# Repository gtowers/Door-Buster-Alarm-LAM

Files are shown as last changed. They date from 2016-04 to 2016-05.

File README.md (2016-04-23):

# Door-Buster-Alarm-LAM
This project is to develop a battery operated magnetic box that will be attached to manufacturing panels at LAM. 
The box has several criteria, but the most important ones are that the box detect panel doors when they are opened.  I have tested this once when the only requirement was that the siren go off for 20 seconds and a light continues to flash until the operator corrects the situation. The customer tested the box, and then came back with several new criteria.  Perhaps unfortunately, but certain decisions have been made, that I do not want to change at this point.    They are as follows:
1)  The battery is required to last 7 days 24 hours a day without the need of a recharge.  This is a customer requirement.
2)  The battery will be 12VDC, that is because the sensor I chose to use requres 11 VDC minimum.  I have chosen an allen-bradley photodetector.
3)   The customer has requested that there be some way that administration can look at the history as the box travels down the "assembly line".  Creating a history of when the box has alarmed.
4)   The customer wants a protective "cage" for the alarm and horn so that if dropped, the beacon/horn won't be damaged.
5)  I am using a lithium polymer battery.  Charging this battery requires a "2 cable" set up.  The customer would like this to become a more simple 1 cable plug
6)  The customer wants a battery sensor that will let them know when the battery is drained to make sure that the battery is charged whenever required.
7)  The customer did not like the looks of the box.  I found a local vendor who has provided me with a box of brushed stainless steel, so this requirement has been satisfied.

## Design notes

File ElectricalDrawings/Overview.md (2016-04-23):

The first sketch, done in autocad electric - only used the arduino, photoelectric sensor and some relays.  
Rev 2_1 is the system broken down and is simply the voltage regulator to change voltage from 12 Volts, used for the arduino down to 3.2 Volts so that I can add the XBee as a stand alone.  My idea is to have it in sleep mode.  It's function is to be in sleep mode it will be used to track the remaining power on the battery.
The drawings are also converted to PDF for general review.

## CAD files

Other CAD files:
ElectricalDrawings/E01_R3.dwg
ElectricalDrawings/E01_R2.dwg
ElectricalDrawings/E01.dwg

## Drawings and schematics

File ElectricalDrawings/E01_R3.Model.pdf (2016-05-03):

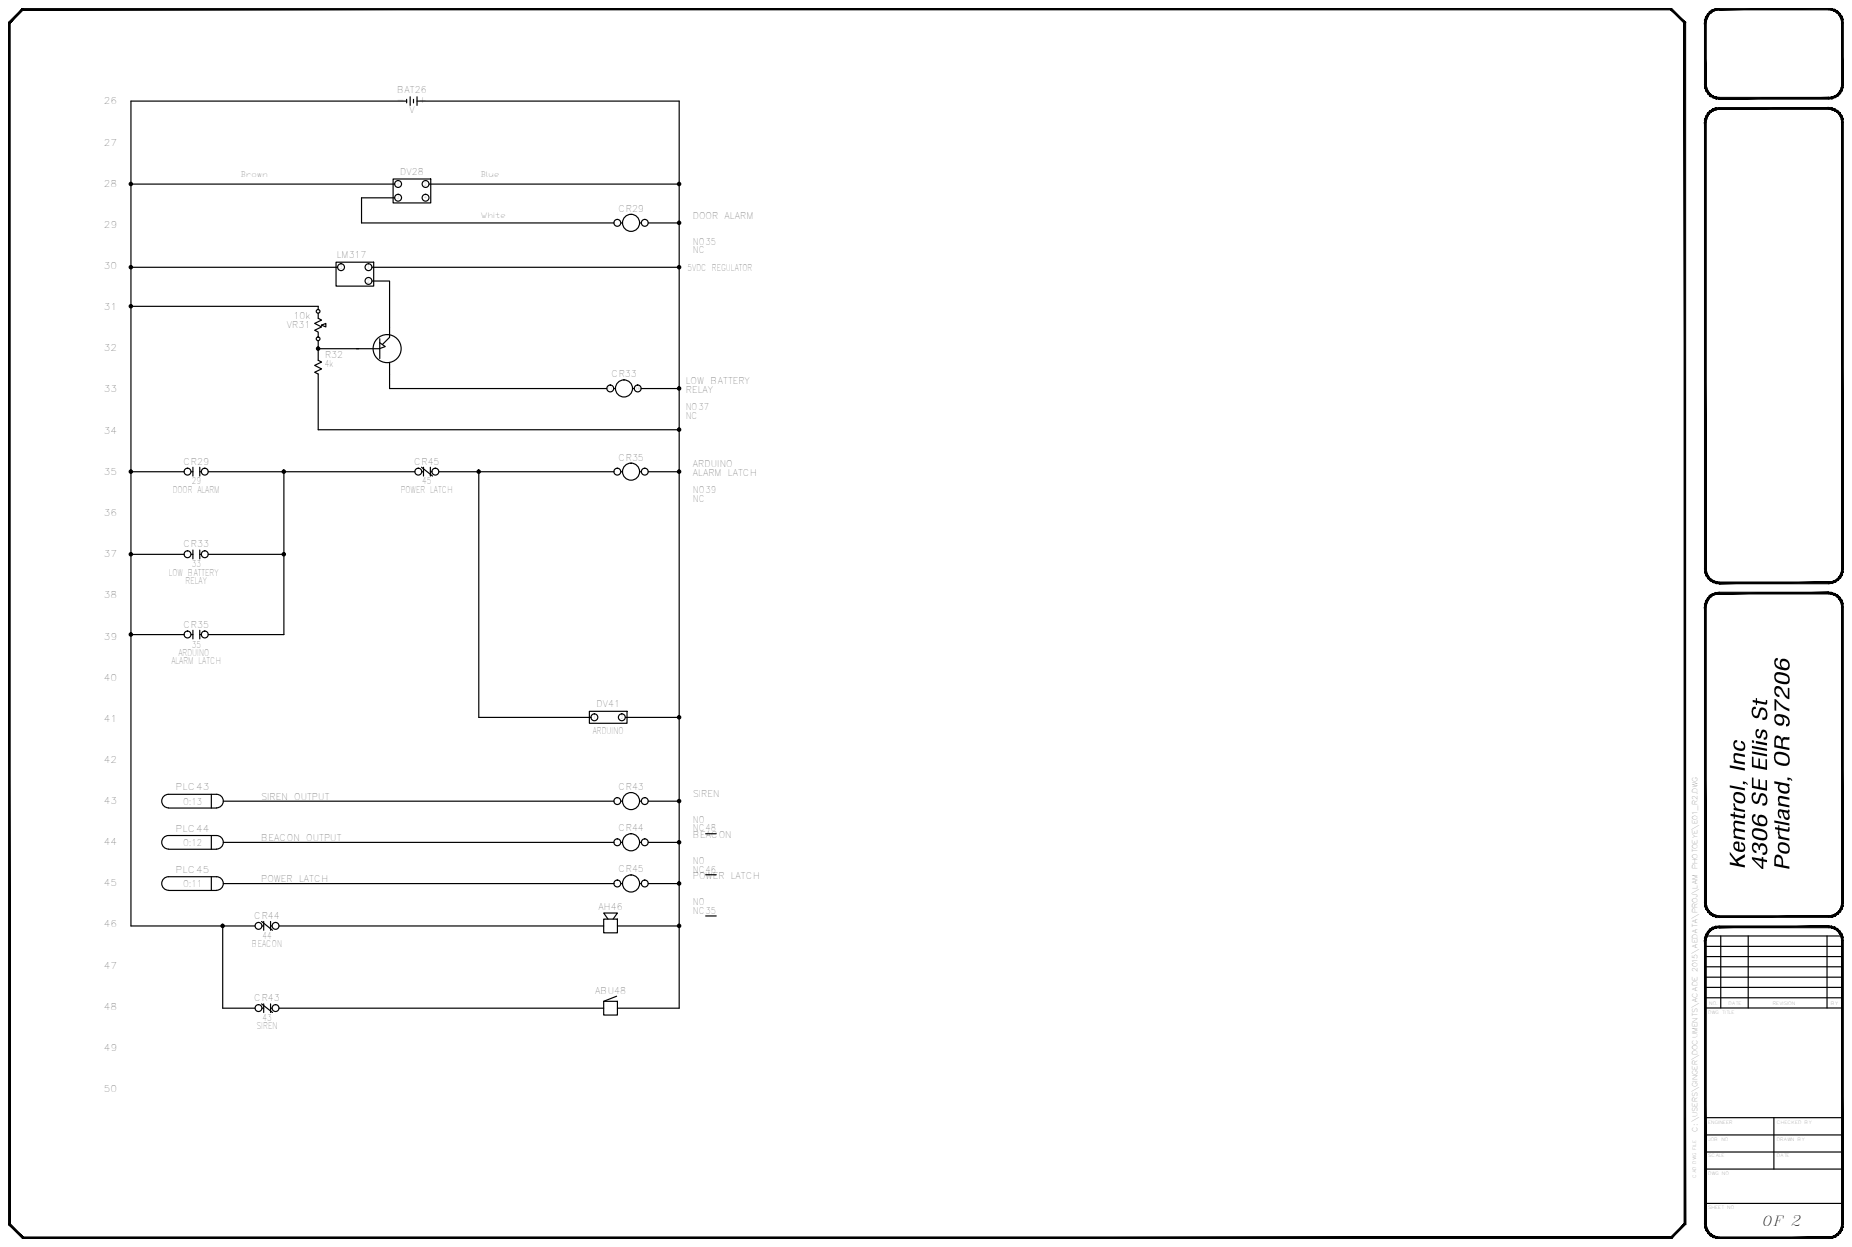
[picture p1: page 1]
DATE; REVISION; BY DWG TITLE; CHECKED BY DRAWN BY DATE ENGINEER JOB NO DWG NO CAD DWG FILE; SCALE; OF SHEET NO; + BAT26; 2 Brown; Blue; NCNO35 DOOR ALARM CR29 AH46 ABU48 PLC43; SIREN OUTPUT O:13; NCNO48 SIREN CR43 PLC44; BEACON OUTPUT O:12; NCNO46 BEACON CR44 PLC45; POWER LATCH O:11; NCNO35 POWER LATCH CR45 44 BEACON CR44 43 SIREN CR43; 5VDC REGULATOR; NCNO37 RELAY LOW BATTERY CR33; NCNO39 ALARM LATCH ARDUINO CR35 29 DOOR ALARM CR29 33 RELAY LOW BATTERY CR33 35 ALARM LATCH ARDUINO CR35; White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

C:\USERS\GINGER\DOCUMENTS\ACADE 2015\AEDATA\PROJ\LAM PHOTOEYE\E01_R2.DWG 26272829303132333435363738394041424344454647484950

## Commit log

2016-04-24 Create Arduino-Code-Template
2016-04-24 Update Arduino-Code-Template
2016-04-25 Create Local_Code_042516
    Added code for Battery Detect Low Voltage Alarm
2016-05-03 Voltage Regulator/PNP Switch
    Modified drawings to add a voltage regulator and a PNP transistor to turn on and off the Low Battery.
    [E01_R3.dwg]
